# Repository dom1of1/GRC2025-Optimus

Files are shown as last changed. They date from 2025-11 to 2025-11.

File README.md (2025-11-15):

# OPTIMUS V2 — Ghana Robotics Competition 2025 (Smart City Builders Challenge)

**MicroPython-powered robot designed for the Ghana Robotics Competition (Engineers League, Smart City Builders Challenge).**
Built using the **Xplore Bot kit** and a **Raspberry Pi Pico**, OPTIMUS V2 combines autonomous bridge repair, Bluetooth manual operation, and 3D-printed attachments to complete city-building and cleanup tasks.

---

## Table of Contents

* [Overview](#overview)

  * [Challenge Context](#challenge-context)
* [Repository Structure](#repository-structure)
* [Robot Summary](#robot-summary)
* [Hardware Overview](#hardware-overview)
* [Software Architecture](#software-architecture)
* [Quick Start (Flash & Run)](#quick-start-flash--run)

  * [Bluetooth Commands](#bluetooth-commands)
* [Behavior Summary](#behavior-summary)

  * [Autonomous Mode](#autonomous-mode-mandatory-30-seconds)
  * [Manual Mode](#manual-mode)
* [Mechanical Design](#mechanical-design)
* [Calibration](#calibration)
* [Rebuilding OPTIMUS V2](#rebuilding-optimus-v2)
* [Documentation & Media](#documentation--media)
* [Credits](#credits)

---

## Overview

### Challenge Context

The **Smart City Builders Challenge** tasks participants to design robots addressing three real-world problems in sustainable cities:

1. **Fixing a Broken Bridge** – repairing road infrastructure before autonomous cars arrive.
2. **Building Essential Services** – constructing schools, hospitals, and workplaces using color-coded blocks.
3. **Cleaning the City** – collecting rubbish balls and disposing them in bins.

Each match lasts **3 minutes**, beginning with a **30-second autonomous mode** (worth double points), followed by a **manual mode** (Bluetooth-controlled). Teams must score as many points as possible without external assistance.

---

## Repository Structure

```
├── docs/
│   ├── Engineering_Notebook.pdf
│   └── Game_Rules.pdf
├── models/
│   └── attachments/
│       ├── BAR.STL
│       ├── clipper_left.STL
│       ├── clipper_right.STL
│       ├── GEAR 9.STL
│       ├── holder.STL
│       ├── Long rack.STL
│       ├── Motor_Holder.STL
│       ├── RACK.STL
│       ├── ROUND.STL
│       ├── slider_left.STL
│       └── slider_right.STL
├── schemes/
│   └── wiring_diagram.png
├── src/
│   ├── main.py
│   └── utils.py
├── videos/
│   └── GRC_Optimus_demo.mp4
├── LICENSE
├── README.md
├── requirements.txt

```

---

## Robot Summary

| Component | Description |
| --- | --- |
| **Name** | OPTIMUS V2 |
| **Controller** | Raspberry Pi Pico (MicroPython) |
| **Drive System** | 4-wheel tank drive (DC motors via L298N drivers) |
| **Power Supply** | 7.4V Li-ion battery pack |
| **Communication** | HC-05 Bluetooth module (UART0, 9600 baud) |
| **Autonomous Inputs** | 2 start buttons (Red = GPIO 2, Blue = GPIO 6) |
| **Outputs** | 4 DC motors, 3 servos |
| **Attachments** | Rear bridge pusher + front dual-servo gripper |

---

## Hardware Overview

### Core Components

| Component | Purpose | Notes |
| --- | --- | --- |
| Raspberry Pi Pico | Main brain | Runs MicroPython code (v1.22+) |
| 4x DC Motors | Movement | Controlled by L298N drivers (PWM) |
| 2x L298N Modules  | Motor control | Each drives 2 motors |
| 3x Servos | Gripper lift and claws | Temporarily disables one motor pin when in use |
| HC-05 Bluetooth | Manual control | UART0 pins (GP0 = TX, GP1 = RX) |
| 2x Start Buttons  | Side selection | Red = GPIO 2, Blue = GPIO 6 |
| Power Source | 7.4V battery | Common ground with Pico |

*See* [`schemes/wiring_diagram.png`](schemes/wiring_diagram.png) *for detailed pin mapping.*

---

## Software Architecture

```bash
src/
├── main.py      # Main program (autonomous + manual control)
└── utils.py     # Movement, servo, and behavior utilities
```

* **`main.py`** handles startup, side selection, and switching between autonomous and manual modes.
* **`utils.py`** contains helper functions for movement, servo control, and timing calibration.

---

## Quick Start (Flash & Run)

1. **Flash MicroPython** to the Raspberry Pi Pico (via Thonny or `esptool`).
2. **Copy Files**: Upload `src/main.py` and `src/utils.py` to the Pico’s root directory.
3. **Wire Components**: Follow [`schemes/wiring_diagram.png`](schemes/wiring_diagram.png) to connect motors, servos, Bluetooth, and buttons.
4. **Power the Robot** and press:

   * **Red button** → Run *Red-side autonomous routine*.
   * **Blue button** → Run *Blue-side autonomous routine*.
5. After the autonomous phase or when Bluetooth input is received, the robot automatically switches to **manual control mode**.

### Bluetooth Commands

| Command | Action |
| --- | --- |
| `F` | Move forward  |
| `B` | Move backward |
| `L` | Turn left |
| `R` | Turn right |
| `S` | Stop |
| `1` | Lower arms |
| `2` | Raise arms |
| `3` | Open gripper  |
| `4` | Close gripper |

---

## Behavior Summary

### Autonomous Mode (Mandatory, 30 seconds)

* Starts upon pressing Red/Blue button.
* Executes bridge repair task based on field side.
* Each side routine uses pre-timed motion (via `calc_time(distance_cm)` calibration).
* Bluetooth input cancels autonomous mode immediately.

#### Autonomous Routines

| Side | Behavior Summary |
| --- | --- |
| **Red**  | Moves forward ≈ 88 cm, turns toward bridge, aligns, and pushes pallets into place. |
| **Blue** | Mirror version of Red with ≈ 70 cm forward motion. |

#### Scoring Reference (from Game Manual)

| Task | Autonomous  | Manual | Notes |
| --- | --- | --- | --- |
| Pallet placed correctly | 40 pts | 20 pts | Double in autonomous |
| Fixed bridge before carbots arrive | +10 bonus | — | — |
| Carbot deviation | −30 penalty | — | — |

---

### Manual Mode

* Activates automatically after autonomous mode or via Bluetooth input.
* Allows fine control for:

  * Collecting and stacking building blocks (school, hospital, workplace)
  * Cleaning the city (rubbish balls)

#### Building Rules

* Blocks must be stacked **Copper → Violet → Grey**.
* Each correctly placed block: **+5 points**.
* Wrong color order: **−10 penalty**.
* Complete structure in correct zone: **+50 bonus**.

#### Cleanup Rules

| Task | Autonomous | Manual | Notes |
| --- | --- | --- | --- |
| Rubbish deposited | 10 pts | 5 pts  | Must fully enter bin |
| Mishandled/dropped container | — | −5 pts | — |

---

## Mechanical Design

| Module | Description |
| --- | --- |
| **Drive System** | 4-wheel tank configuration for stability and turning control. |
| **Front Gripper** | Dual 3D-printed rectangular arms (servo-controlled). |
| **Gripper Functions** | Lift (servo 1), Open/Close (servos 2 & 3). |
| **Rear Attachment** | Fixed pusher plate for bridge repair. |

3D models for attachments available in [`models/attachments`](models/attachments)
---

## Calibration

Motion timing is based on travel distance (40.5 cm/s baseline). The following formula is used for consistent movement:

```python
# utils.py
# Convert distance (cm) to time (s)
time = 1.8 * (distance_cm / 40.5)
```

Adjust the multiplier based on battery level and motor friction.

---

## Rebuilding OPTIMUS V2

To replicate the full robot:

1. Assemble the Xplore Bot chassis.
2. Attach rear bridge pusher and dual-servo front gripper.
3. Wire components per `schemes/wiring_diagram.png`.
4. Flash MicroPython to the Pico.
5. Copy `main.py` and `utils.py` into root.
6. Test motion timing with small distances before full run.
7. Calibrate servo angles in `utils.py`.
8. Verify Bluetooth communication using serial monitor or RC Controller app.

---

## Documentation & Media

* [`docs/Engineering_Notebook.pdf`](docs/Engineering_Notebook.pdf) — Build log, team notes, design iterations.
* [`docs/Game_Rules.pdf`](docs/Game_Rules.pdf) — Full official Smart City Builders Challenge manual.
* [`schemes/wiring_diagram.png`](schemes/wiring_diagram.png) — Electrical wiring reference.
* [`models/attachments`](models/attachments) — 3D models for attachments.
* [`videos/GRC_Optimus_demo.mp4`](videos/GRC_Optimus_demo.mp4) — Demo run footage.

---

## Credits

* Team **Optimus** — University of Ghana, October 2025
* **Members:**

  * Dominic Fatonade: Programmer — [mrdominicfatonade@gmail.com](mailto:mrdominicfatonade@gmail.com) || [dom1of1](https://github.com/dom1of1)
  * Bess-Marie Wuddah-Martey: Designer — [bessmariewuddahmartey@gmail.com](mailto:bessmariewuddahmartey@gmail.com) || [bess](https://github.com/--)
  * Anastasia Andoh: Builder — [andohanastasia3@gmail.com](mailto:andohanastasia3@gmail.com) || [Anadhilah](https://github.com/Anadhilah)
* **Event Organizer:** Fireflyio Robotics — Ghana Robotics Competition 2025

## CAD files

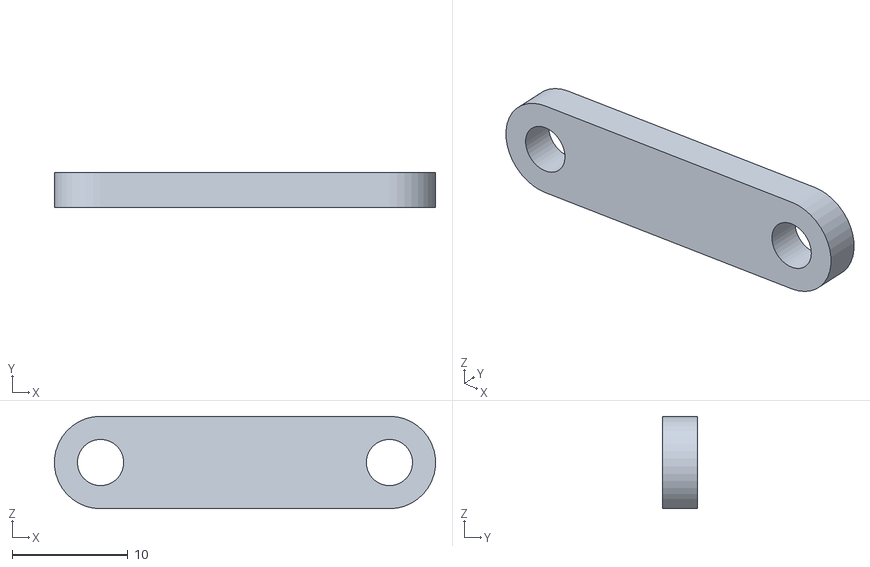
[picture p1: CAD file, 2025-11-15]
models/attachments/holder.STL
33.0 x 3.00 x 8.00

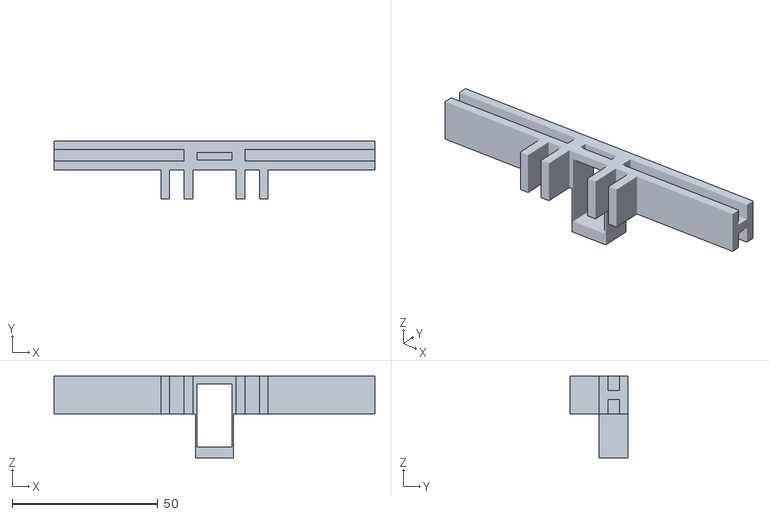
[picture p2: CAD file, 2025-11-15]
models/attachments/BAR.STL
110.0 x 20.0 x 28.0

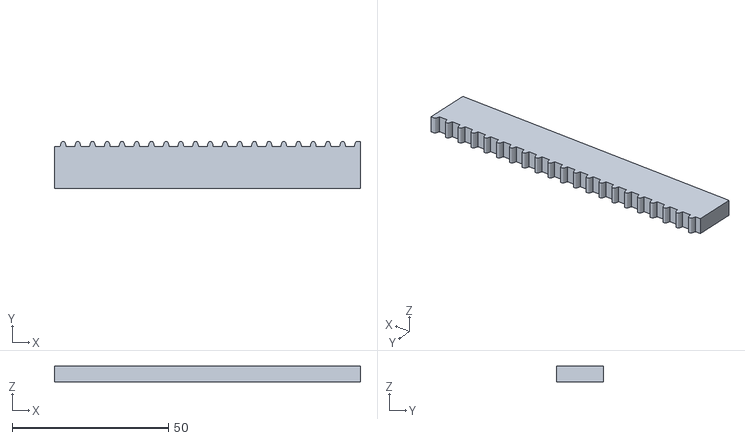
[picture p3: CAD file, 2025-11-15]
models/attachments/RACK.STL
98.0 x 15.0 x 5.00

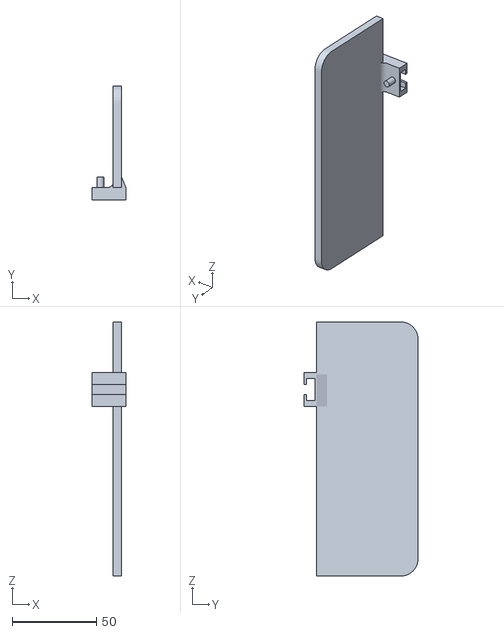
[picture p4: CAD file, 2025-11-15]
models/attachments/slider_left.STL
20.0 x 67.5 x 150.5

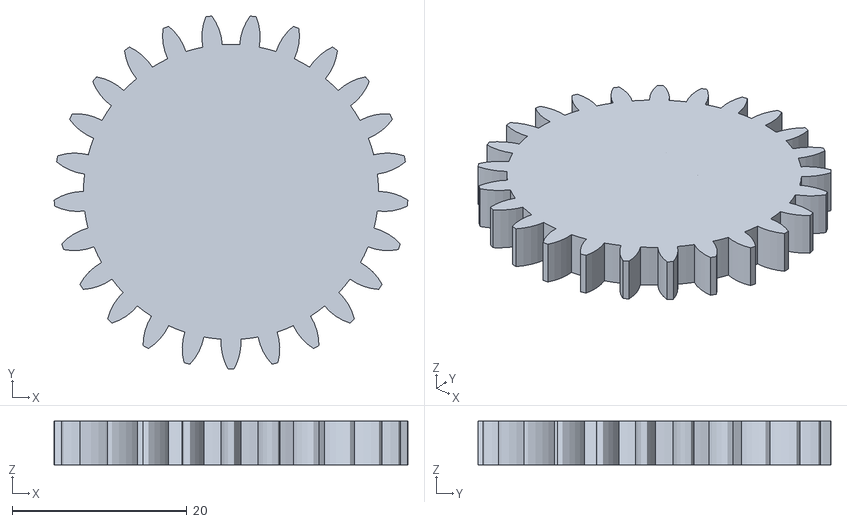
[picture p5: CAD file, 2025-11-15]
models/attachments/GEAR 9.STL
40.5 x 40.4 x 5.00

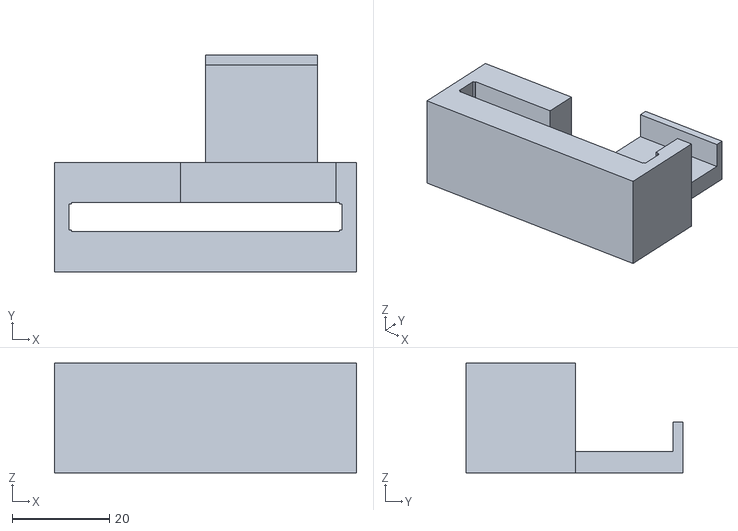
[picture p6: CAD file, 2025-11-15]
models/attachments/clipper_left.STL
62.0 x 44.5 x 22.5

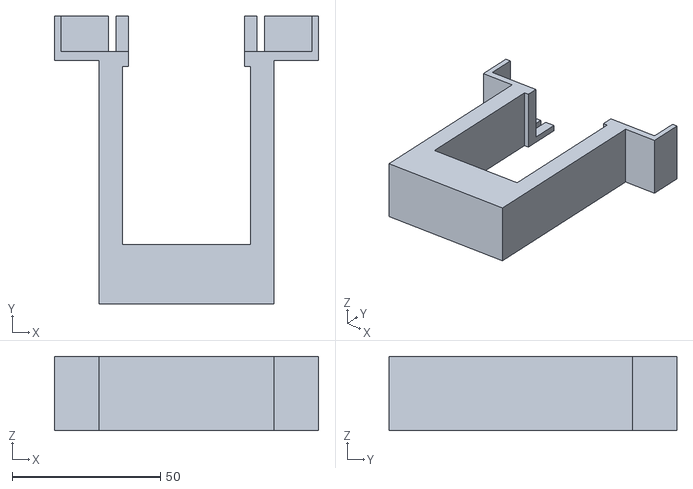
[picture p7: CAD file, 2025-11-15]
models/attachments/Motor_Holder.STL
89.0 x 97.0 x 25.0

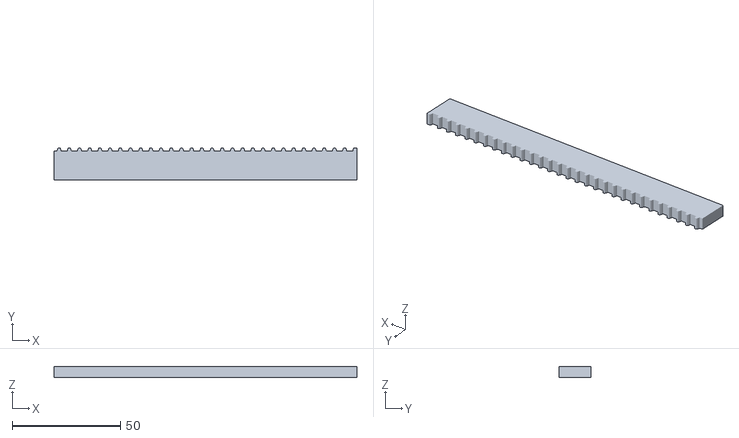
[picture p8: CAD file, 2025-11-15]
models/attachments/Long rack.STL
140.0 x 15.0 x 5.00

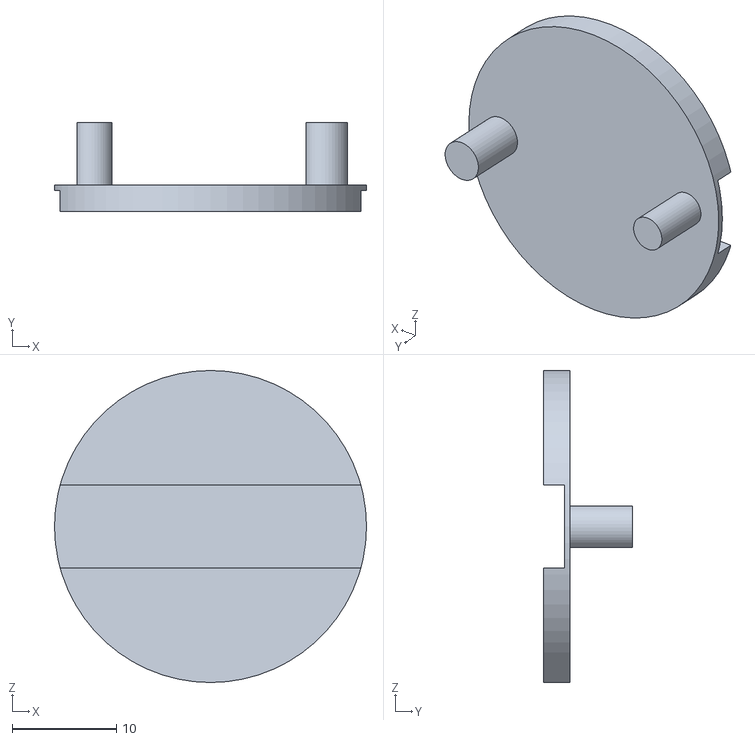
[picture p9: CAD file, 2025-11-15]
models/attachments/ROUND.STL
30.0 x 8.56 x 30.0

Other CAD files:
models/attachments/slider_right.STL
models/attachments/clipper_right.STL

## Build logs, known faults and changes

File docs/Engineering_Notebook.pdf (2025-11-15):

# OPTIMUS

## ENGINEERING NOTEBOOK

GHANA ROBOTICS COMPETITION Engineers League

University of Ghana
October 2025

### 1. Team Introduction

Team Members:
- Dominic Fatonade, Programmer, Level 200
- Bess-Marie Wuddah-Martey, Designer, Level 100
- Anastasia Andoh, Builder, Level 300

### 2. Project Goals 2.1. League Challenge

Smart City Builders Challenge: Creating sustainable infrastructure, community services, and clean environments in growing African cities.
2.2.Problem Statement: Our robot must complete missions related to fixing infrastructure, building essential services, and managing urban waste to support sustainable city development.

### 2.3. Goals:

Complete the three required missions:
- Fixing a Broken Bridge (Road Infrastructure)
- Building Essential Services (School, Hospital, Workplace)
- Cleaning the City (Rubbish Collection)
Points are maximized by designing effective autonomous and manual control strategies. Practice teamwork, problem-solving, and innovation while connecting the challenge to SDG 9 (Industry, Innovation, and Infrastructure) and SDG 11 (Sustainable Cities and Communities).

### 3. Brainstorming and Strategy 3.1. Initial Ideas:

- We considered separating the tasks between each bot so they each specialized in some tasks. This idea was scrapped since teams will be randomized.
- We resolved to start by assembling a base driving robot with Xplore Bot parts from Firefly.io and tried to get the basic movements down before we started discussing attachments to gradually add.
- We explored our options for controlling the bot in manual mode using a Bluetooth module. We considered using the RC Bluetooth Controller app.
- We discussed, experimented with and designed some grab and lift mechanisms for building blocks such as a crane and a grabbing arm.
- We experimented with different turning methods (diagonal vs left-right motor control).
- We sketched and designed some potential 3D-printed interchangeable attachments.
- We explored VSCode, Thonny and block-based coding to see which is best for our work.

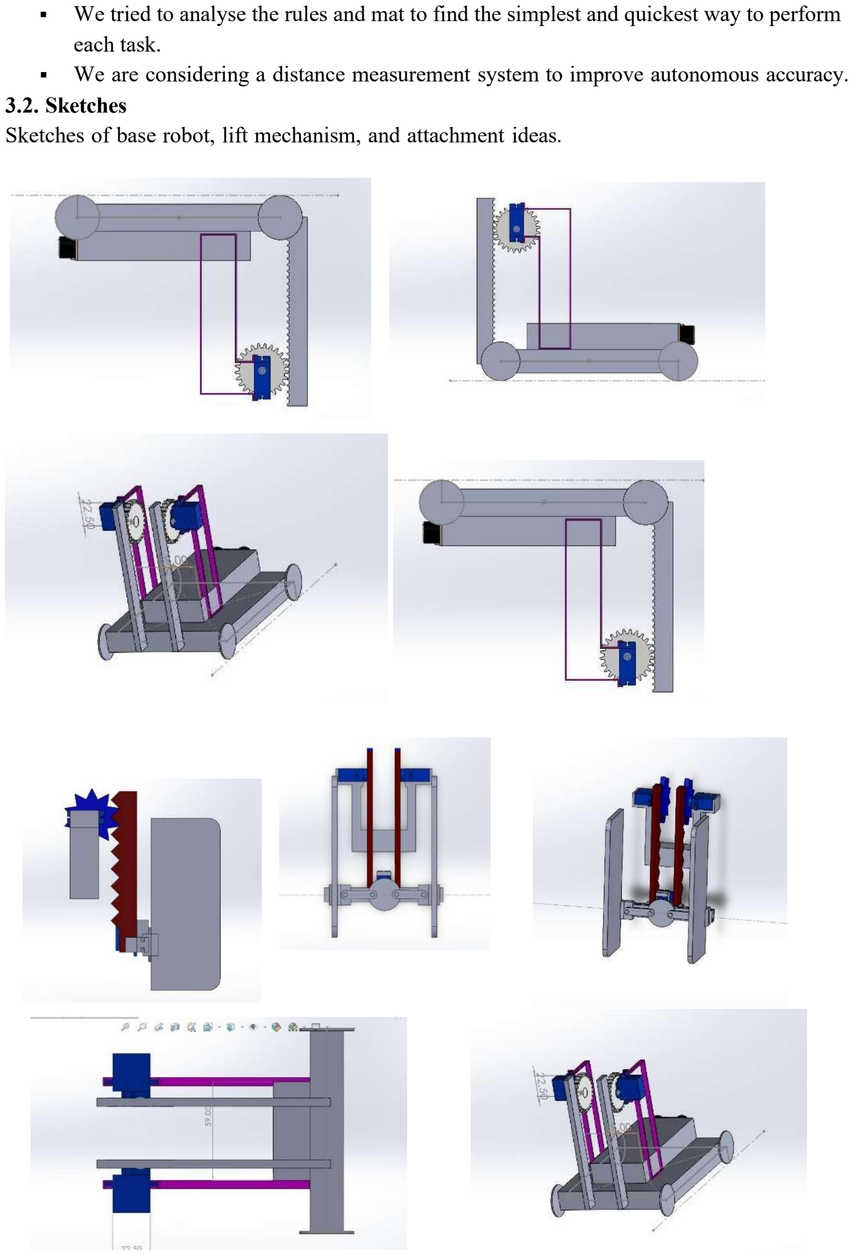
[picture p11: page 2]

- We tried to analyse the rules and mat to find the simplest and quickest way to perform each task.
- We are considering a distance measurement system to improve autonomous accuracy.

### 3.2. Sketches

Sketches of base robot, lift mechanism, and attachment ideas.

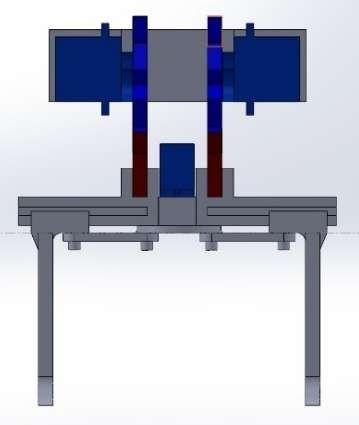
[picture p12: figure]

Strategy Options

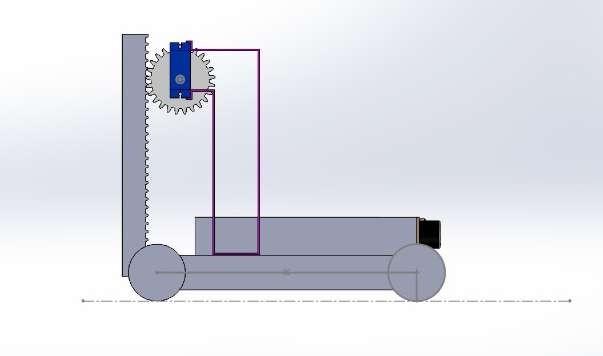
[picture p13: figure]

- Prioritize bridge repair in autonomous mode. This prevents the -30pts penalty, earns bonus points, and doubles our score for completing the task.
- Use manual mode to stack building blocks for schools/hospitals/workplaces. This is an intricate and specific task granting scalable points with multipliers for taller structures.
- Considering writing code for the bot to build in autonomous mode, but only simple structures.
- Fall-back option for autonomous mode is rubbish collection in case our alliance partner is also doing the bridge in autonomous.
- Assign remaining time to rubbish collection since this has lower points per action but grants steady points, is reliable and easy to repeat, and thus easier to program and may not require complex attachments.

### 3.3. Pros and Cons

- Bridge repair first: High reward and safety bonus; requires speed and precision.
- Building essential services: High scoring potential with multipliers if we can do it autonomously; more complex, risk of time overruns.
- Rubbish collection: Simple and consistent; low points compared to other tasks.

### 3.4. Chosen Idea and Why

- The team decided to focus on bridge repair during autonomous since it prevents penalties, secures bonus points, and earns double. We will fall back on rubbish collection in autonomous mode in case our alliance partner handles bridge repair.
- In manual mode, effort will shift to building essential services (for big multipliers) while using leftover time for rubbish collection to secure easy additional points.
- This approach balances high-value tasks (bridge and buildings) with low-risk scoring (rubbish), ensuring steady results.

### 4. Design Process

For each robot version, we followed the VEX Design Process, which is: Define the problem, Brainstorm, Research, Develop Ideas, Choose the Best Solution, Build a Prototype, Test and Evaluate, Improve, then finally, Share.

Here are our weekly progress and versions as we progressed in our development:

Week 1
- Built the base robot.

- Familiarized with programming interface(Thonny).
- Read the challenge document and developed strategy.
- Started designing extra parts needed for the challenge.
- Took inventory of faulty parts.

Week 2
- Agreed on a game strategy.
- Discussed grab and lift mechanism.
- Figured out pins for front motors
- Tested turning methods. Initially used diagonal wheel control, but improved turning by controlling wheels side-by-side (left vs right). Turning became smoother and sharper.
- Built a prototype grabbing mechanism

Week 3
- Fixed the forward alignment of the bot, making the bot moved straight.
- Modelled a prototype of the lifting mechanism.
- Looked into using blocks code editor for the bot. Could be easier to program the servos and other motors with it.
- Attempted to measure distance with the bot.

Week 4
- Changed DC motor in the attachment to a server motor.
- Compiled an engineering notebook.
- Fixed the bot’s drift.
- Attached an ultrasonic sensor.

Week 5
- Tested the ultrasonic sensor
- Finalized attachment designs
- Finalized documentation

Version 1 – 23/09/2025
- Sketch/Photo

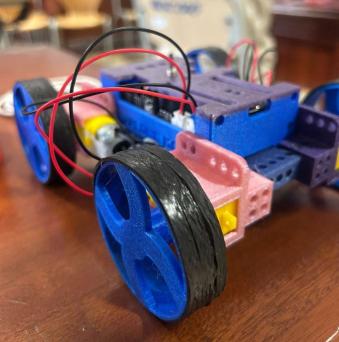
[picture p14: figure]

- Testing: Basic movement and turning mechanism
- Code structure:

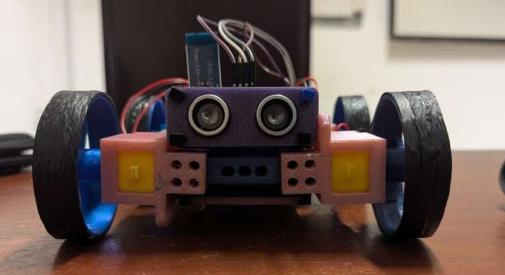
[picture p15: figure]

from machine import PWM, UART, Pin from time import sleep
import utime

# Set the relay pins as output pins # motor 1

ENA = PWM(Pin(10))
m1_forward = Pin(12, Pin.OUT) m1_back = Pin(11, Pin.OUT)

# motor 2

ENB = PWM(Pin(13))
m2_back = Pin(14, Pin.OUT) m2_forward = Pin(15, Pin.OUT)

# motor 3

ENC = PWM(Pin(26))
m3_forward = Pin(17, Pin.OUT)
- Components Used: Raspberry pi pico, Wheels, Motors
- Design Changes: Turning mechanism
- Testing Results: we could connect to the Thonny IDE and run commands, as well as configured the motor pin numbers.

Version 2 – 07/10/2025
- Sketch/Photo
- Testing: Measure distance using the ultrasonic sensor, connect to a mobile remote controller using the Bluetooth module
- Components Used: Ultrasonic sensor, Bluetooth module
- Design Changes: Added an ultrasonic sensor and Bluetooth module
- Testing Results: we were able to work with distances and write code dependent on it thanks to the IR sensor, as well as control our bot using a mobile phone thank to the bluetooth module.

### 5. Programming 5.1. Code Environment: Visual Studio Code, Xplore IDE

5.2. Sensors/Motors: Initially used diagonal motor control, later switched to left vs right wheel control for smoother turns. We implemented n ultrasonic sensor for discerning distances.

### 5.3. Code Snippets:

m3_back = Pin(16, Pin.OUT)

# motor 4

END = PWM(Pin(21))
m4_forward = Pin(19, Pin.OUT) m4_back = Pin(18, Pin.OUT)

# Bluetooth setup

uart = UART(0, 9600)

# speed of the bot

speed = 65025 # 0 - 65025

ENA.duty_u16(55000)
ENB.duty_u16(52000)
ENC.duty_u16(55000)
END.duty_u16(52000)

def forward():
m1_forward.on()
m1_back.off()
m2_back.off()
m2_forward.on()
m3_forward.on()
m3_back.off()
m4_forward.on()
m4_back.off()

def back():
m1_forward.off()
m1_back.on()
m2_back.on()
m2_forward.off()
m3_forward.off()
m3_back.on()
m4_forward.off()
m4_back.on()

def right():
m1_forward.on()
m1_back.off()
m2_back.on()
m2_forward.off()
m3_forward.on()
m3_back.off()
m4_forward.off()
m4_back.on()

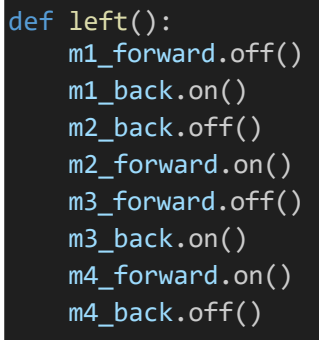
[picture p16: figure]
def left(): m1_forward.off() m1_back.on() m2_back.off() m2_forward.on() m3_forward.off() m3_back.on() m4_forward.on() m4_back.off()
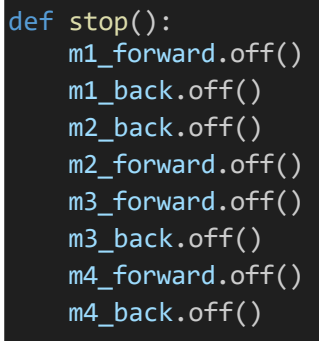
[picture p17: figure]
def stop(): m1_forward.off() m1_back.off() m2_back.off() m2_forward.off() m3_forward.off() m3_back.off() m4_forward.off() m4_back.off()
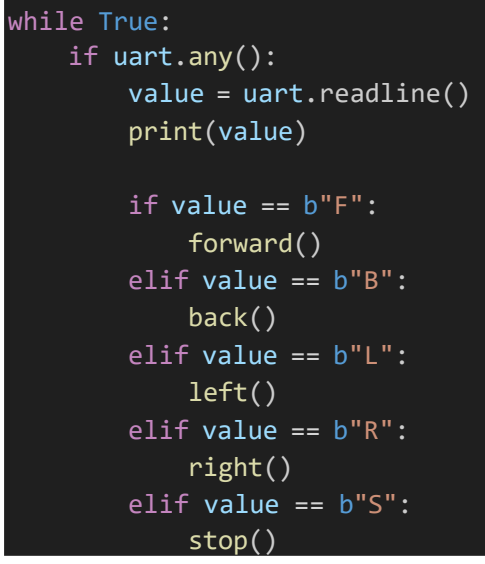
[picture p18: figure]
while True: if uart.any(): value = uart.readline() print(value); if value == b"F": forward() elif value == b"B": back() elif value == b"L": left() elif value == b"R": right() elif value == b"S": stop()

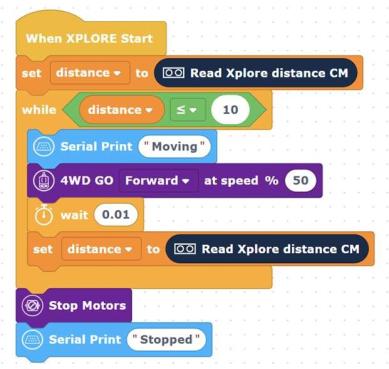
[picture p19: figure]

### 6. Challenges and Solutions

- Programming Issues:
- Turns were not behaving as expected for the rear wheels, but we fixed that when we switched to using blocks to code.
- Xplore IDE was not defining variables in the blocks to python conversion.
- Mechanical Issues:
- Initial turning method (diagonal wheels) caused rough, inefficient turns. We switched to left/right motor configuration, resulting in smoother, sharper turning.
- Some components that we were given in the Xplore bot box were of low quality (incorrectly printed wheel bridge, busted battery case, lose wheels in the motor, to mention a few) leading to ill-fitted parts and some discrepancies that affect the performance of our bot.
- Wobbly Wheels.
- Hybrid Issues:
- Wobbly wheels, so the bot couldn’t move in a straight line, paired with excessive power in one set of motors. Solved by changing the motor holders and reducing the power in the left set of motors.

### 7. Teamwork and Roles 7.1. Collaboration Notes:

All members of both teams from the University of Ghana brainstormed strategy together and divided early tasks (base building, programming exploration, mechanism design documentation) effectively, with everyone participating in each part whilst each specializing in their assigned roles

### 7.2. Individual Learnings:

- Importance of testing multiple approaches (turning logic) and cross-verifying results.
- Refreshing our knowledge of the blocks code editor
- Programming a raspberry pi pico

### 8. Final Robot Design

- Description
The final version of our robot, Optimus V2, is a compact and stable four-wheeled robot designed for both autonomous and manual control modes. It uses a Raspberry Pi Pico microcontroller as its brain, connected to four DC motors configured in a left-right wheel control system for smoother and sharper turns. The body is built on the Xplore Bot chassis, with improved motor holders for stability and alignment.
An ultrasonic sensor is mounted at the front of the robot to detect obstacles and measure distances during autonomous runs. This allows the robot to approach or stop precisely when interacting with mission elements like the bridge or rubbish bins. A Bluetooth module is integrated for manual control via a mobile RC Controller app, providing easy manoeuvring during manual game segments.
We utilize interchangeable attachments, such as a lifting arm for building essential services and a scoop-like attachment for rubbish collection. These can be swapped easily depending on the mission requirements.
- Effectiveness
This final robot design effectively fulfils the team’s strategy by balancing stability, modularity, and precision:
- The ultrasonic sensor improves the accuracy of autonomous tasks like bridge repair and rubbish collection.
- The Bluetooth control system allows responsive and smooth manual driving for stacking and positioning during building missions.
- The compact structure ensures the bot can navigate tight spaces on the challenge mat without colliding with obstacles.
- The interchangeable attachment system gives flexibility to adapt to different missions quickly, without needing to rebuild the bot.
- Adjusted motor speeds and wheel alignment corrections ensure consistent straight movement and precise turning, critical for both scoring reliability and time efficiency.
Overall, the robot performs consistently, is easy to control, and can complete its core missions efficiently under competition conditions.
- Trade-offs
- Speed vs. Control: To maintain stability and precision, we slightly reduced motor speed. This makes turns smoother but sacrifices some acceleration.
- Dimension Restrictions: some attachments increased the robot’s dimensions slightly, requiring fine-tuning of attachment designs.
- Complexity vs. Reliability: We opted against adding advanced automation for building tasks in favour of a simpler, more reliable manual stacking process.
- Material Quality: Some components from the Xplore kit were imperfectly manufactured (e.g., misaligned wheel bridge, loose fits). We compensated through realignment and reinforcement but couldn’t achieve perfect symmetry. Despite these trade-offs, Optimus V2 achieved a strong balance between precision, durability, and flexibility enabling it to complete multiple challenge missions effectively and consistently.

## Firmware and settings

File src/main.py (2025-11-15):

from time import sleep
from utils import set_speed, red_autonomous_behavior, blue_autonomous_behavior, forward, backward, left, right, stop, servo_up, servo_down, servo_open, servo_close, Start, uart

# Set initial speed
set_speed(50000)

# Mode tracking
autonomous_mode = True
autonomous_completed = False

Start()
print("Started")
sleep(3)

# Clear any initial UART data from Bluetooth module connection
while uart.any():
    uart.read()

#Main loop
while True:
    if autonomous_mode and not autonomous_completed:
        # Run autonomous behavior and check for manual override
        if blue_autonomous_behavior():
            # Manual override detected
            autonomous_mode = False
        else:
            # Autonomous completed normally
            autonomous_completed = True
            autonomous_mode = False
            stop()
    else:
        # Manual mode
        if uart.any():
            value = uart.readline()
            print(value)

            if value == b'F':
                forward()
            elif value == b'B':
                backward()
            elif value == b'L':
                left()
            elif value == b'R':
                right()
            elif value == b'S':
                stop()
            elif value == b'1':
                servo_down()
            elif value == b'2':
                servo_up()
            elif value == b'3':
                servo_open()
            elif value == b'4':
                servo_close()

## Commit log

2025-11-09 Major refactor:
    - Add engineering notebook and game rules documents;
    - Add wiring diagram for robot connections.
    - Include 3D model files for attachments and a demo video.
    -Update Readme
2025-11-15 feat: Add STL files for 3D models of attachments
    [BAR.STL, GEAR 9.STL, Long rack.STL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]
2025-11-15 refactor: Move main.py and utils.py files in src folder. Remove placeholder stl files in models/attachments.
